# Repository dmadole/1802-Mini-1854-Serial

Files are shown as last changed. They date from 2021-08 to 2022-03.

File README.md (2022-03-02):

# 1802-Mini-1854-Serial
This is the 1854 UART serial card for the [1802/Mini](https://github.com/dmadole/1802-Mini) system. It supports the following features:

* Sixteen baud rates from 300 to 57600
* Jumpers to determine default baud rate at reset
* Baud rate can be changed by software
* No rare chips except the CDP1854 itself
* Supports group I/O port expansion
* Jumper-selected address 2/3, 4/5, or 6/7
* Jumper-selected interrupt poll bit on EF1-EF4
* Supports input flow control using software-driven bit
* Supports output flow control using software-read ES pin
* Jumper-selected transmit and receive interrupts or only for receive
* Both DCE (female) and DTE (male) 9-pin ports, populate either or both
* A TTL-level port with “standard” FTDI-type USB cable pinout

Gerber files for the PCBs and PDF schematics can be found in [Releases](https://github.com/dmadole/1802-Mini-1854-Serial/releases).

BOMS and any applicable errata or other notes can be found in [notes](https://github.com/dmadole/1802-Mini-1854-Serial/tree/main/notes).

For availability of kits and bare PCBs please see http://madole.net/1802/mini/kits

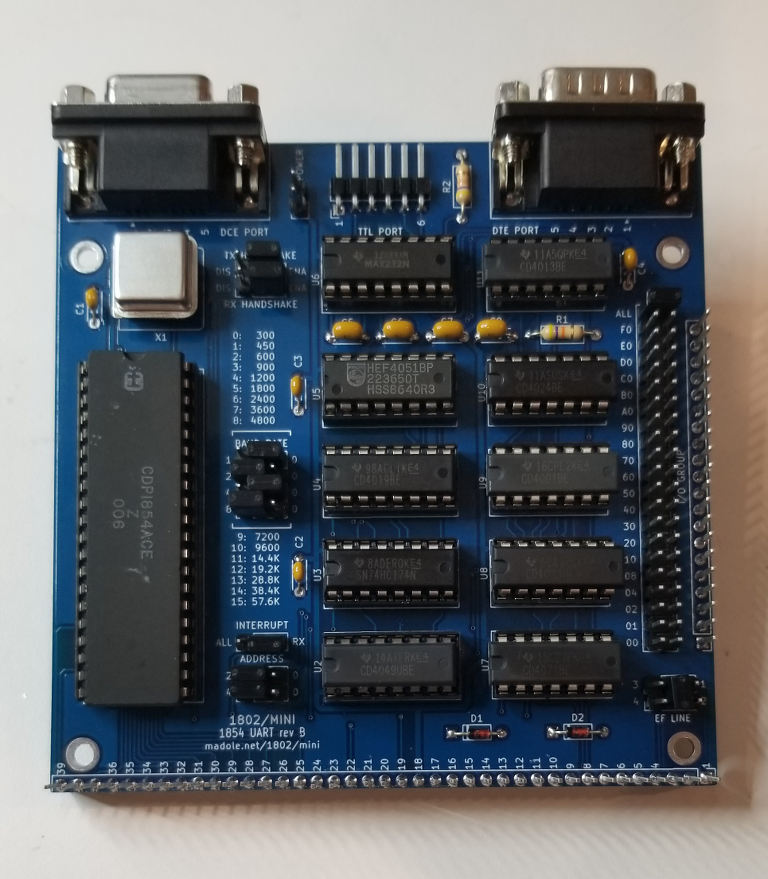
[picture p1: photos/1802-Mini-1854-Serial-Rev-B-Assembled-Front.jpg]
1802/Mini 1854 Serial Front

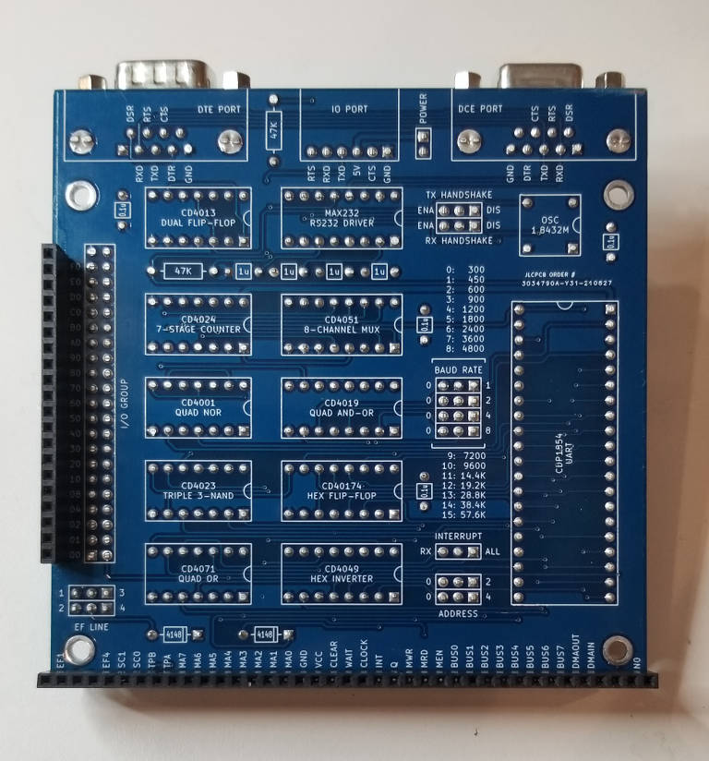
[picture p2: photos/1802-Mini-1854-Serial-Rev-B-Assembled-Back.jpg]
1802/Mini 1854 Serial Back


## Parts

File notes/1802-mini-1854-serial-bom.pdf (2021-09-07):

### 1854 SERIAL INTERFACE

Qty | Description | Manufacturer Manufacturer # | Vendor | Vendor #

Integrated Circuits
1 | CDP1854 | U2 | Harris | CDP1854ACE | Obsolete CDP1854ACE
1 | CD4001 | U1 | TI | CD4001BE | Digikey | 296-2028-ND
1 | CD4013 | U6 | TI | CD4013BE | Digikey | 296-2033-5-ND
1 | CD4019 | U9 | TI | CD4019BE | Digikey | 296-2038-5-ND
1 | CD4023 | U5 | TI | CD4023BE | Digikey | 296-2041-ND
1 | CD4024 | U8 | TI | CD4024BE | Digikey | 296-2042-ND
1 | CD4049 | U3 | TI | CD4049UBE | Digikey | 296-2055-5-ND
1 | CD4051 | U10 | TI | CD4051BE | Digikey | 296-2057-5-ND
1 | CD4071 | U4 | TI | CD4071BE | Digikey | 296-2062-ND
1 | CD40174 (or 74C174 or 74HC174) | U7 | TI | SN74HC174N | Digikey | 296-1579-5-ND
1 | MAX232 | U11 | TI | MAX232N | Digikey | 296-1402-5-ND
1 | Oscillator half-size 1.8432Mhz | X1 | ECS | ECS-2100A-018 | Digikey | XC231-ND

Discrete Components
2 | Resistor 1/4 watt 47K | R1-2 | Stackpole | CF14JT47K0 | Digikey | CF14JT47K0CT-ND
2 | Diode 1N4148 | D1-2 | ON Semi | 1N4148 | Digikey | 1N4148FS-ND
4 | Ceramic capacitor 0.1uF radial 0.2" | C1,2,5,6 | Vishay | K104K10X7RF5UH5 | Digikey | BC2665CT-ND
4 | Ceramic capacitor 1.0uF radial 0.2" | C4,7,8,9 | Vishay | K105K20X7RF5UH5 | Digikey | BC2668CT-ND

Interconnect and Mechanical
1 | Socket 20 pin 0.1" long tail | | Samtec | SSQ-120-03-T-S | Digikey | SAM1206-20-ND
1 | Straight header 2 pins 0.1" | | Sullins | PREC002SAAN-RC | Digikey | S1012EC-02-ND
11 | Straight header 3 pins 0.1" | | Sullins | PREC003SAAN-RC | Digikey | S1012EC-03-ND
1 | Right-angle header 6 pins 0.1" | | Sullins | PREC006SBAN-M71RC | Digikey | S1112EC-06-ND
12 | Jumper shunts 0.1" | | Sullins | STC02SYAN | Digikey | S9000-ND
1 | Straight dual row header 21 position | | Sullins | PREC021DAAN-RC | Digikey | S2012EC-21-ND
4 | 0.5 inch standoff spacer | | RAF | 4505-440-AL-7 | Digikey | 1772-2065-ND
1 | DE-9 right-angle plug pc-mount | | Assman | A-DS 09 A/KG-T2S | Digikey | AE10968-ND
1 | DE-9 right-angle receptacle pc-mount | | Assman | A-DF 09 A/KG-T2S | Digikey | AE10921-ND

Integrated Circuit Sockets
1 | DIP socket 40 pin 0.6" | U2 | On Shore | ED40DT | Digikey | ED3048-5-ND
5 | DIP socket 14 pin 0.3" | U1,4-6,8 | On Shore | ED14DT | Digikey | ED3045-5-ND
5 | DIP socket 16 pin 0.3" | U3,7,9-11 | On Shore | ED16DT | Digikey | ED3046-5-ND
1 | DIP socket 4 pin in 8 pin frame 0.3" | X1 | On Shore | ED08DT | Digikey | ED3044-5-ND

Circuit Board and Expansion
1 | Circuit Board | | Madole | | JLCPCB
1 | Socket 39 pin 0.1" long tail | | Samtec | SSQ-139-03-T-S | Digikey | SAM1206-39-ND

Note: Part numbers, manufacturers, and vendors are typical of what is supplied. Substitutions may be made based on availability at time of ordering.

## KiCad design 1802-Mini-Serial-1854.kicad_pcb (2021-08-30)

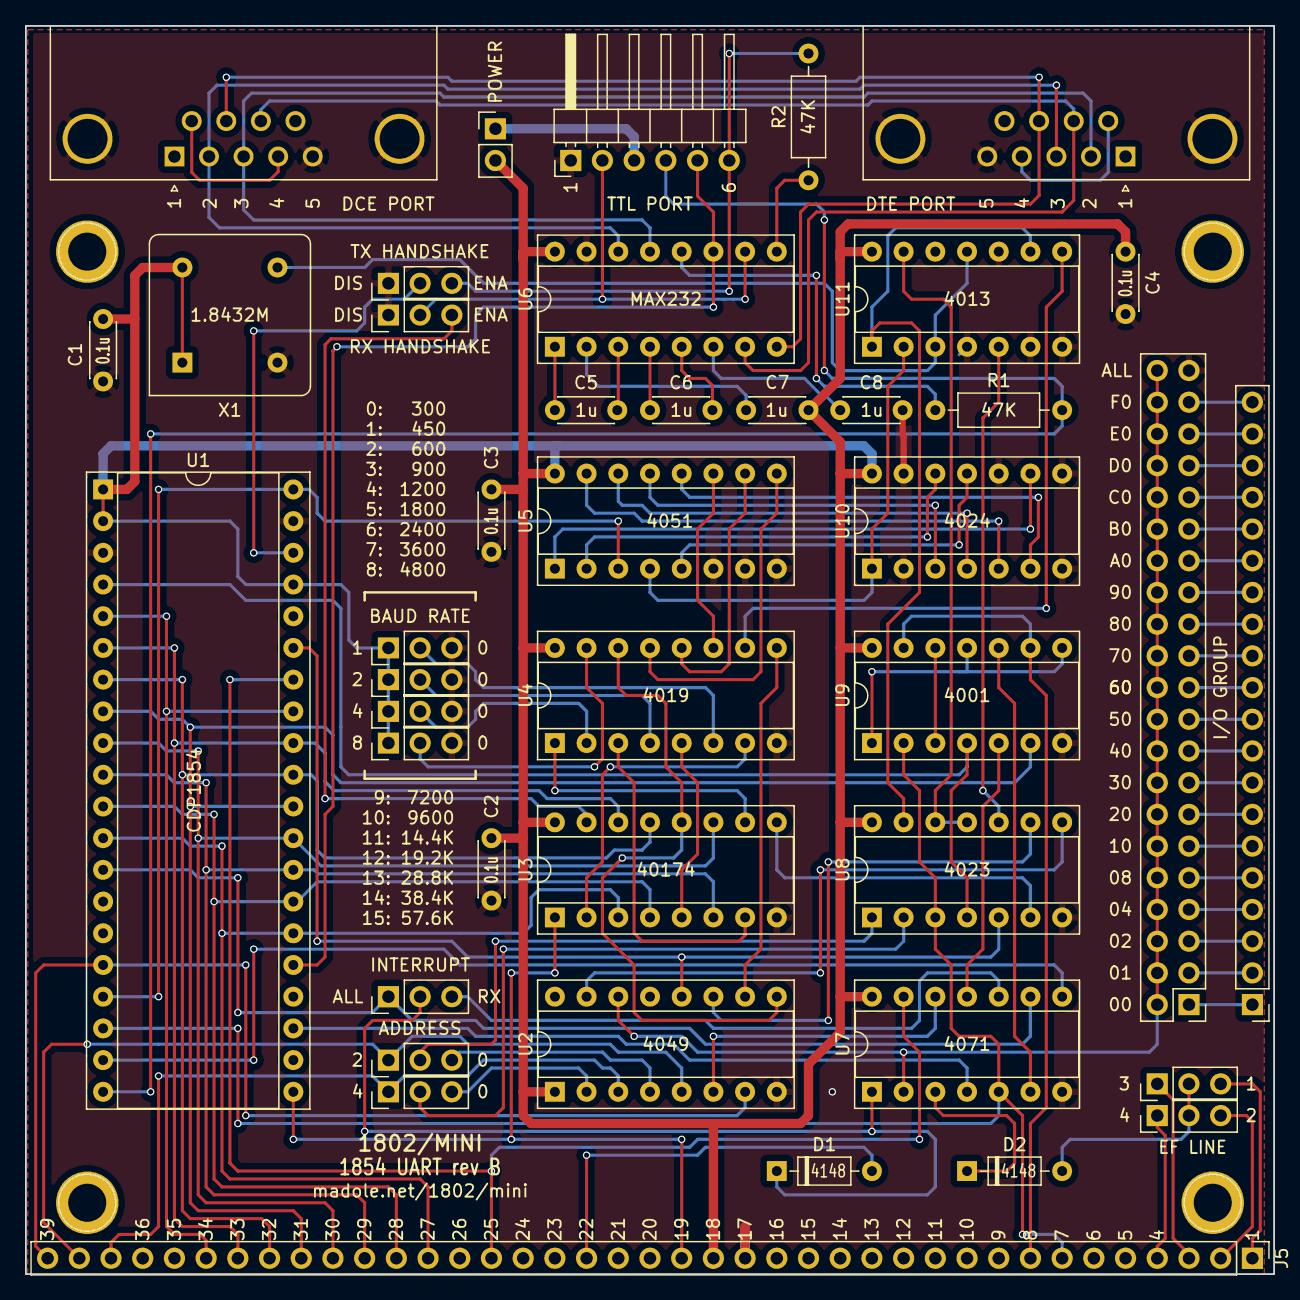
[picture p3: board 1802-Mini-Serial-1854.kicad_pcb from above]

Board: 2 copper layers, 100.0 x 100.0 mm, 46 parts (0 on the bottom side), 112 nets.

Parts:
C1, C2, C3, C4: 0.1u; C_Disc_D4.3mm_W1.9mm_P5.00mm
C5, C6, C7, C8: 1uF; C_Disc_D4.3mm_W1.9mm_P5.00mm
D1, D2: 4148; D_DO-35_SOD27_P7.62mm_Horizontal
J1, J2, J3, J4: Mount; 1pin
J5: Expansion; PinHeader_1x39_P2.54mm_Vertical
J6: GRP_EXP; PinHeader_1x20_P2.54mm_Vertical
J7: GRP_SEL; PinHeader_2x21_P2.54mm_Vertical
J8: DCE; DSUB-9_Female_Horizontal_P2.77x2.84mm_EdgePinOffset7.70mm_H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
J9: DTE; DSUB-9_Male_Horizontal_P2.77x2.84mm_EdgePinOffset7.70mm_Hou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
J10: TTL; PinHeader_1x06_P2.54mm_Horizontal
JP1: N2; PinHeader_1x03_P2.54mm_Vertical
JP2: RX_HSHK; PinHeader_1x03_P2.54mm_Vertical
JP3: EF1/3; PinHeader_1x03_P2.54mm_Vertical
JP4: EF2/4; PinHeader_1x03_P2.54mm_Vertical
JP5: TX_HSHK; PinHeader_1x03_P2.54mm_Vertical
JP6: BR8; PinHeader_1x03_P2.54mm_Vertical
JP7: BR4; PinHeader_1x03_P2.54mm_Vertical
JP8: BR2; PinHeader_1x03_P2.54mm_Vertical
JP9: BR1; PinHeader_1x03_P2.54mm_Vertical
JP10: INT_SRC; PinHeader_1x03_P2.54mm_Vertical
JP11: Jumper_2_Open; PinHeader_1x02_P2.54mm_Vertical
JP13: N1; PinHeader_1x03_P2.54mm_Vertical
R1, R2: R; R_Axial_DIN0207_L6.3mm_D2.5mm_P10.16mm_Horizontal
U1: CDP1854; DIP-40_W15.24mm_Socket
U2: 4049; DIP-16_W7.62mm_Socket
U3: 74LS174; DIP-16_W7.62mm_Socket
U4: 4019; DIP-16_W7.62mm_Socket
U5: 4051; DIP-16_W7.62mm_Socket
U6: MAX232; DIP-16_W7.62mm_Socket
U7: 4071; DIP-14_W7.62mm_Socket
U8: 4023; DIP-14_W7.62mm_Socket
U9: 4001; DIP-14_W7.62mm_Socket
U10: 4024; DIP-14_W7.62mm_Socket
U11: 4013; DIP-14_W7.62mm_Socket
X1: 1.8432; Oscillator_DIP-8

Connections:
/BUS0: J5.27, U1.12, U1.26, U3.3
/BUS1: J5.28, U1.11, U1.27, U3.4
/BUS2: J5.29, U1.10, U1.28, U3.6
/BUS3: J5.30, U1.9, U1.29, U3.11
/BUS5: J5.32, U1.7, U1.31, U3.13
/BUS6: J5.33, U1.6, U1.32, U3.14
/BUS7: J5.34, U1.5, U1.33
BUS4: J5.31, U1.8, U1.30, U9.6
CS1: U1.23, U7.4
CS3: U1.35, U2.12, U8.5
GND: C1.2, C2.2, C3.2, C4.2, C8.2, J5.17, J7.41, J8.0, J8.5, J9.0, J9.5, J10.1, JP2.1, JP5.1, JP6.3, JP7.3, JP8.3, JP9.3, U1.3, U1.39, U2.8, U3.8, U4.8, U5.6, U5.7, U5.8, U6.15, U7.7, U8.7, U9.7, U10.2, U10.7, U10.8, U10.10, U10.13, U11.4, U11.6, U11.7, U11.10, X1.4
LATCH: U3.9, U8.6
N0: J5.39, U1.16, U2.7
N1: J5.38, JP13.1, U2.5
N2: J5.37, JP1.1, U2.3
unnamed: C5.1, U6.1
unnamed: C5.2, U6.3
unnamed: C6.1, U6.4
unnamed: C6.2, U6.5
unnamed: C7.2, U6.2
unnamed: C8.1, U6.6
unnamed: D1.1, JP10.2, U7.1
unnamed: D2.1, U7.3
unnamed: D2.2, JP3.2, JP4.2
unnamed: J6.1, J7.1
unnamed: J6.2, J7.3
unnamed: J6.3, J7.5
unnamed: J6.4, J7.7
unnamed: J6.5, J7.9
unnamed: J6.6, J7.11
unnamed: J6.7, J7.13
unnamed: J6.8, J7.15
unnamed: J6.9, J7.17
unnamed: J6.10, J7.19
unnamed: J6.11, J7.21
unnamed: J6.12, J7.23
unnamed: J6.13, J7.25
unnamed: J6.14, J7.27
unnamed: J6.15, J7.29
unnamed: J6.16, J7.31
unnamed: J6.17, J7.33
unnamed: J6.18, J7.35
unnamed: J6.19, J7.37
unnamed: J6.20, J7.39
unnamed: J8.2, J9.3, U6.14
unnamed: J8.3, J9.2, U6.13
unnamed: J8.4, J8.6
unnamed: J8.7, J9.8, U6.8
unnamed: J8.8, J9.7, U6.7
unnamed: J9.4, J9.6
unnamed: J10.2, JP5.2, U6.10
unnamed: J10.3, JP11.1
unnamed: J10.4, R1.2, U1.20
unnamed: J10.5, U1.25, U6.11
unnamed: J10.6, JP2.3, R2.2
unnamed: JP1.2, U8.2
unnamed: JP1.3, U2.2
unnamed: JP2.2, U1.38
unnamed: JP5.3, U3.15
unnamed: JP6.2, U4.15
unnamed: JP7.2, U4.2
unnamed: JP8.2, U4.4
unnamed: JP9.2, U4.6
unnamed: JP10.3, U7.10
unnamed: JP13.2, U8.1
unnamed: JP13.3, U2.4
unnamed: R1.1, U6.12
unnamed: R2.1, U6.9
unnamed: U1.17, U1.40, U5.3
unnamed: U2.6, U7.12
unnamed: U2.9, U3.12, U4.14
unnamed: U2.10, U4.9
unnamed: U2.11, U8.9
unnamed: U2.15, U8.8
unnamed: U3.2, U4.7
unnamed: U3.5, U4.5
unnamed: U3.7, U4.3
unnamed: U3.10, U4.1
unnamed: U4.11, U5.11
unnamed: U4.12, U5.10
unnamed: U4.13, U5.9
unnamed: U7.6, U9.10
unnamed: U7.11, U9.5
unnamed: U9.1, U9.8, U9.11
unnamed: U9.3, U9.12
unnamed: U5.4, U10.1, U11.2
unnamed: U5.13, U10.3
unnamed: U5.14, U10.4
unnamed: U5.15, U10.5
unnamed: U5.12, U10.6
unnamed: U5.1, U10.9
unnamed: U5.5, U10.11
unnamed: U5.2, U10.12
unnamed: U8.13, U11.1, U11.9
unnamed: U8.10, U11.5
unnamed: U4.10, U11.8
unnamed: U11.3, U11.11, X1.5
unnamed: U8.11, U8.12, U11.13
TPA: J5.8, U9.9, U9.13
TPB: J5.7, U1.18, U7.5, U8.3, U9.2
VCC: C1.1, C2.1, C3.1, C4.1, C7.1, J5.18, JP6.1, JP7.1, JP8.1, JP9.1, JP11.2, U1.1, U1.2, U1.37, U2.1, U3.16, U4.16, U5.16, U6.16, U7.14, U8.14, U9.14, U10.14, U11.14, X1.1, X1.8
~CLEAR: J5.19, U1.21, U3.1
~CS2: U1.4, U8.4, U9.4
~DA: U1.19, U7.8
~EF1: J5.1, JP3.3
~EF2: J5.2, JP4.3
~EF3: J5.3, JP3.1
~EF4: J5.4, JP4.1
~GROUP: J7.2, J7.4, J7.6, J7.8, J7.10, J7.12, J7.14, J7.16, J7.18, J7.20, J7.22, J7.24, J7.26, J7.28, J7.30, J7.32, J7.34, J7.36, J7.38, J7.40, J7.42, U2.14, U7.2
~INT: D1.2, J5.22
~MRD: J5.25, U1.34, U7.13
~UINT: JP10.1, U1.13, U7.9

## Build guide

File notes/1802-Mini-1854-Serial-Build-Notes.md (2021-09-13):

# 1802/Mini 1854 Serial Assembly Notes

Follow usual assembly practices, which I will not document here. I recommend installing the lowest-height components first (resistors, diodes, right-angle connectors), then the next higher (sockets), and so on.

There are a lot of options on this board and it's important to make sure all of them have been selected correctly. The board will not work as expected without nearly all options selected one way or the other.

Please see any [applicable errata](https://github.com/dmadole/1802-Mini-1854-Serial/tree/main/notes) before assembling.

## Capacitor Values

Note that there are two different values of ceramic capacitor on this board, 0.1uF and 1.0uF. Please be sure to install the correct value in the correct location. The 0.1uF go at C1-4, and the 1.0uF go at C5-8.

## Power Jumper

When installed, the POWER jumper connects the +5 volt pin on the TTL serial connector to the power bus of the board. This could be used when it is desired to power an off-board accessory, like a level-shifter, from the port, or it could be used to input power to the 1802/Mini from the TTL serial connector, for example, to power the system from a USB converter. Unless you are specifically intending a function like this, it is recommended to leave this jump off.

## Handshaking

The TX HANDSHAKE and RX HANDSHAKE jumpers control whether hardware handshake signals are utilized. When either jumper is set to DIS then the corresponding signal is permanently asserted. In the case of RX HANDSHAKE, the handshake signal from the serial port connectors are then disregarded. In the case of TX HANDSHAKE, the output handshake signal on the serial power connectors is permanently asserted. If there is no need to perform hardware handshaking, these jumpers can be set to DIS to avoid the possibility of a handshake signal not being asserted causing the serial power to not transmit or receive, such as from a misconfigured cable.

Note that handshaking is not supported by the BIOS drivers in ROM and the output handshake will be asserted and the input handshake disregarded in this case regardless of the jumper settings. Use of handshaking requires a software-loadable driver that implements this additional functionality.

## Baud Rates

The serial interface supports 16 baud rates from 300 to 57600 baud. A table of the jumper settings to select these rates is printed on the silkscreen of the board. These jumper settings determine the default baud rate that is set at reset, and may be overridden under software control later.

## Interrupts

The serial interface is capable of operating interrupt-driven and two modes are supported. The INTERRUPT jumped can be used to select whether interrupts are generated for all events recognized by the 1854 UART, or for receive character events only. Removing this jumper completely will disable interrupts.

The BIOS drivers do not support interrupt-driven operation. The standard software driver supports interrupts for receive characters only; if using this driver, either jumper setting will work, but the RX setting that only generates receive interrupts will produce less processor overhead and so it is recommended.

## Addressing

The serial interface occupies two I/O ports which are set by the address jumpers. The standard configuration is for addresses 6 and 7 which are selected by jumpering the 2 and 4 jumpers to set the base address to 6. This is what is supported by the standard ROM and software drivers and is recommended.

Two-level I/O group selection is also supported, if the systemn contains a group expander board, in which case the desired group address should be jumpered on the I/O group jumpers. If no group expander board is installed, then the jumper should be installed on the ALL setting.

## EF Lines

The serial interface is capable of connecting the interrupt signal, gated with the group-select signal, onto any one of the EF lines. This may be useful for custom polling drivers, or to support faster polling of interrupt-driven devices to determine which needs service. At this time, this feature is not supported by either the BIOS or software drivers and it is recommended to leave this jumper off.

## Serial Ports

The serial interface has three serial connectors, of which only one should be used at a time. The DTE connector (male) implements the same pin-out as a standard PC-AT serial port, and the DCE connector (female) implements just the opposite, meaning it looks like a PC-AT connector with a "null modem" cable.

The board may be connected to a PC serial power with a straight-through cable to the DCE conennector, or with a "null modem" cable to the DTE connector. For other types of peripherals, cables intended for a PC serial port should be able to be connected directly to the DTE connector.

The TTL port pin-out matches that of many common FTDI-based USB adapter cables, and those may be plugged in directly. When a cable is connected to the TTL port, it will override the input signals from either of the 9-pin ports.

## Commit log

2021-08-26 Fix EF flags
    [1802-Mini-Serial-1854.kicad_pcb, 1802-Mini-Serial-1854.sch]
2021-08-27 Layout fixes
    [1802-Mini-Serial-1854.kicad_pcb, 1802-Mini-Serial-1854.sch]
2021-09-07 Create README.md
    # 1802-Mini-Compact-Flash
    This is the 1854 UART card for the [1802/Mini](https://github.com/dmadole/1802-Mini) system. It supports the following features:
    * Sixteen baud rates from 300 to 57600
    * Jumpers to determine default baud rate at reset
    * Baud rate can be changed by software
    * No rare chips except the CDP1854 itself
    * Supports group I/O port expansion
    * Jumper-selected address 2/3, 4/5, or 6/7
    * Jumper-selected interrupt poll bit on EF1-EF4
    * Supports input flow control using software-driven bit
    * Supports output flow control using software-read ES pin
    * Jumper-selected transmit and receive interrupts or only for receive
    * Both DCE (female) and DTE (ma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
